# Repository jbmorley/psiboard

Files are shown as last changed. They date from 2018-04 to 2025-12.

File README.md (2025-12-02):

# PsiBoard



Psion Series 5 based bluetooth keyboard.



## BOM

### FFC Connector

https://www.digikey.com/en/products/detail/molex/0524372271/3262899

22 Position FFC, FPC Connector Contacts, Bottom 0.020" (0.50mm) Surface Mount, Right Angle

### Reset Switch

https://www.digikey.com/en/products/detail/panasonic-electronic-components/EVQ-P7A01P/4429447

## Development

### Useful Links

- [ZMK Firmware - List of Keycodes](https://zmk.dev/docs/keymaps/list-of-keycodes)
- [ZMK Firmware - Power Management Configuration](https://zmk.dev/docs/config/power)
- [Pro Micro Pinout](https://learn.sparkfun.com/tutorials/pro-micro--fio-v3-hookup-guide/all)

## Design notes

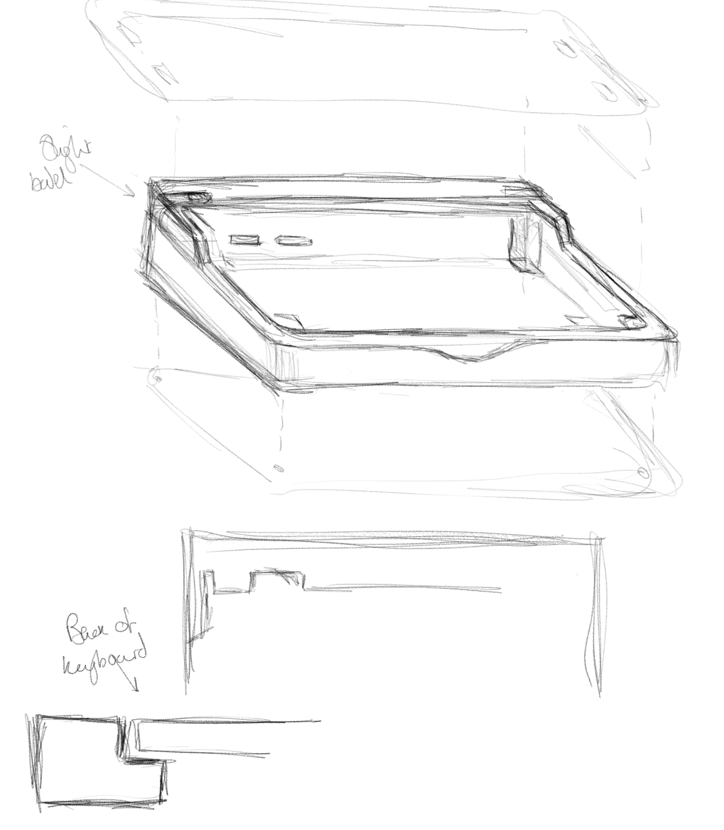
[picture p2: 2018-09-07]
reference/design.png

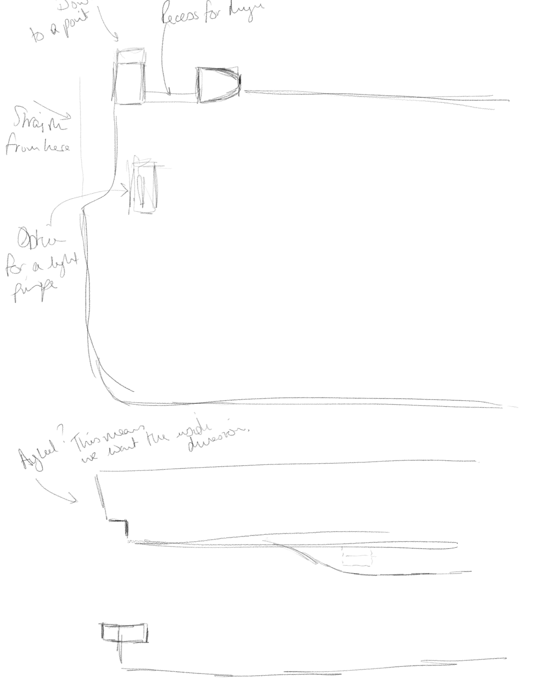
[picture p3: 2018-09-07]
reference/hinge.png

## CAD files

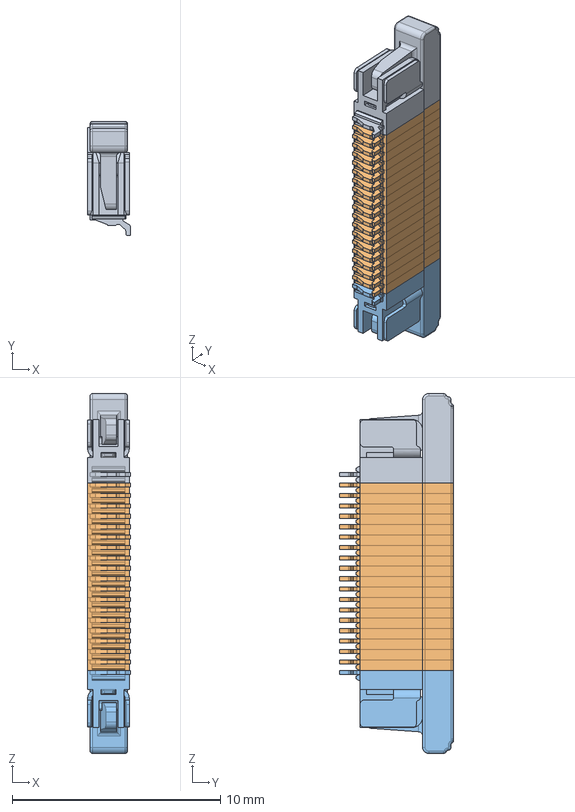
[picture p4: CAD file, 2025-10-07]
pcb/models/f32q_20pin_asm.stp
2.05 x 5.50 x 17.3 mm
F32Q_L
F32Q_M x 18
F32Q_R

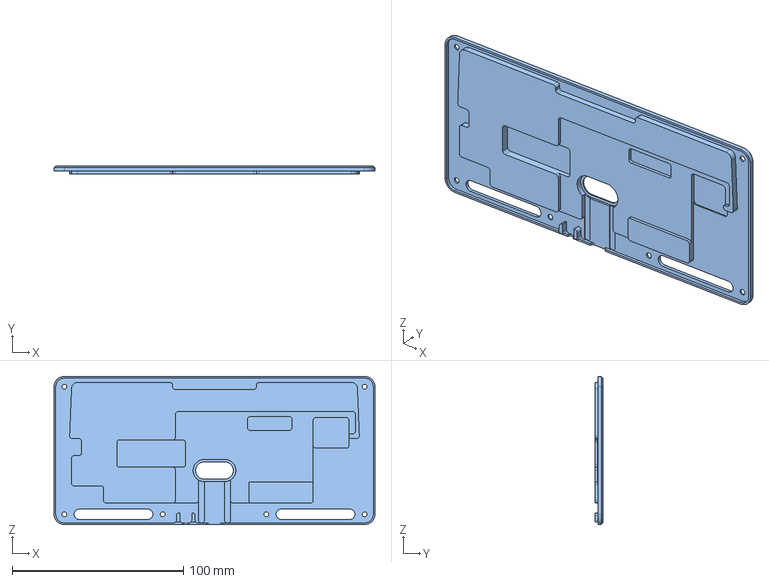
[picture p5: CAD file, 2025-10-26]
manufacture/Keyboard Bottom CNC.step
187.5 x 4.80 x 86.5 mm

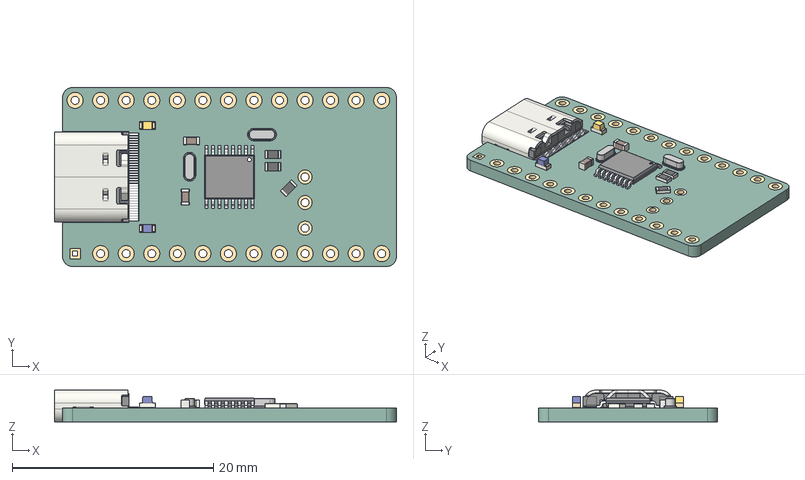
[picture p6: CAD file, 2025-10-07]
pcb/components/nicenano/nicenano.step
34.0 x 17.8 x 3.16 mm
nice!nano v1.0_1
USB_C_Receptacle_16P_TopMnt_Horizontal_GCT_USB4105-xx-A
USB_C_Receptacle_16P_TopMnt_Horizontal_GCT_USB4105-xx-A001
USB_C_Receptacle_16P_TopMnt_Horizontal_GCT_USB4105-xx-A002
USB_C_Receptacle_16P_TopMnt_Horizontal_GCT_USB4105-xx-A003
USB_C_Receptacle_16P_TopMnt_Horizontal_GCT_USB4105-xx-A004
USB_C_Receptacle_16P_TopMnt_Horizontal_GCT_USB4105-xx-A005
USB_C_Receptacle_16P_TopMnt_Horizontal_GCT_USB4105-xx-A006
USB_C_Receptacle_16P_TopMnt_Horizontal_GCT_USB4105-xx-A007
USB_C_Receptacle_16P_TopMnt_Horizontal_GCT_USB4105-xx-A008
USB_C_Receptacle_16P_TopMnt_Horizontal_GCT_USB4105-xx-A009
USB_C_Receptacle_16P_TopMnt_Horizontal_GCT_USB4105-xx-A010
USB_C_Receptacle_16P_TopMnt_Horizontal_GCT_USB4105-xx-A011
USB_C_Receptacle_16P_TopMnt_Horizontal_GCT_USB4105-xx-A012
USB_C_Receptacle_16P_TopMnt_Horizontal_GCT_USB4105-xx-A013
USB_C_Receptacle_16P_TopMnt_Horizontal_GCT_USB4105-xx-A014
USB_C_Receptacle_16P_TopMnt_Horizontal_GCT_USB4105-xx-A015
USB_C_Receptacle_16P_TopMnt_Horizontal_GCT_USB4105-xx-A016
USB_C_Receptacle_16P_TopMnt_Horizontal_GCT_USB4105-xx-A017
USB_C_Receptacle_16P_TopMnt_Horizontal_GCT_USB4105-xx-A018
USB_C_Receptacle_16P_TopMnt_Horizontal_GCT_USB4105-xx-A019
USB_C_Receptacle_16P_TopMnt_Horizontal_GCT_USB4105-xx-A020
USB_C_Receptacle_16P_TopMnt_Horizontal_GCT_USB4105-xx-A021
USB_C_Receptacle_16P_TopMnt_Horizontal_GCT_USB4105-xx-A022
USB_C_Receptacle_16P_TopMnt_Horizontal_GCT_USB4105-xx-A023
USB_C_Receptacle_16P_TopMnt_Horizontal_GCT_USB4105-xx-A024
USB_C_Receptacle_16P_TopMnt_Horizontal_GCT_USB4105-xx-A025
USB_C_Receptacle_16P_TopMnt_Horizontal_GCT_USB4105-xx-A026
USB_C_Receptacle_16P_TopMnt_Horizontal_GCT_USB4105-xx-A027
USB_C_Receptacle_16P_TopMnt_Horizontal_GCT_USB4105-xx-A028
USB_C_Receptacle_16P_TopMnt_Horizontal_GCT_USB4105-xx-A029
USB_C_Receptacle_16P_TopMnt_Horizontal_GCT_USB4105-xx-A030
USB_C_Receptacle_16P_TopMnt_Horizontal_GCT_USB4105-xx-A031
USB_C_Receptacle_16P_TopMnt_Horizontal_GCT_USB4105-xx-A032
USB_C_Receptacle_16P_TopMnt_Horizontal_GCT_USB4105-xx-A033
USB_C_Receptacle_16P_TopMnt_Horizontal_GCT_USB4105-xx-A034
USB_C_Receptacle_16P_TopMnt_Horizontal_GCT_USB4105-xx-A035
Pin9
Pin10
Pin12
Pin11
Pin13
Pin14
Pin15
Pin16
Pin8
Pin7
Pin6
Pin5
Pin4
Pin3
Pin2
Pin1
LED_0603_1608Metric_ON
C_0603_1608Metric x 2
LED_0603_1608Metric_ON_1
Crystal Oscillator x 2
R_0603_1608Metric x 4

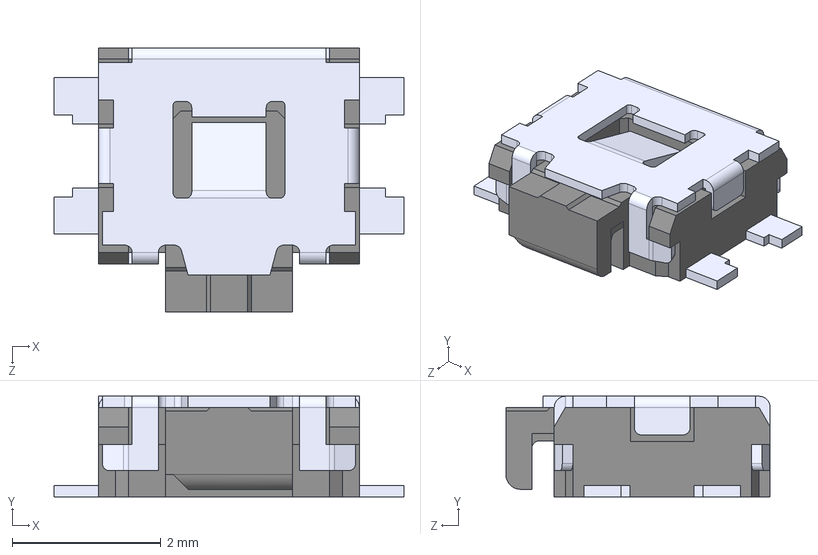
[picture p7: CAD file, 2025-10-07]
pcb/EVQ_P7A01P/EVQ-P7A01P.step
4.70 x 1.35 x 3.55 mm

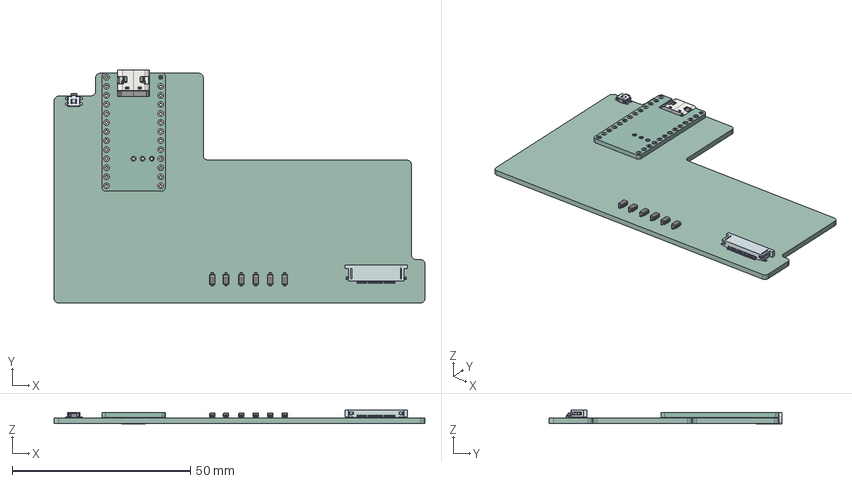
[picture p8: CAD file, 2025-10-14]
pcb/psiboard.step
104.1 x 65.4 x 3.83 mm
D_SOD-123 x 6
EVQ-P7A01P
nice!nano v1.0
USB_C_Receptacle_16P_TopMnt_Horizontal_GCT_USB4105-xx-A
USB_C_Receptacle_16P_TopMnt_Horizontal_GCT_USB4105-xx-A001
USB_C_Receptacle_16P_TopMnt_Horizontal_GCT_USB4105-xx-A002
USB_C_Receptacle_16P_TopMnt_Horizontal_GCT_USB4105-xx-A003
USB_C_Receptacle_16P_TopMnt_Horizontal_GCT_USB4105-xx-A004
USB_C_Receptacle_16P_TopMnt_Horizontal_GCT_USB4105-xx-A005
USB_C_Receptacle_16P_TopMnt_Horizontal_GCT_USB4105-xx-A006
USB_C_Receptacle_16P_TopMnt_Horizontal_GCT_USB4105-xx-A007
USB_C_Receptacle_16P_TopMnt_Horizontal_GCT_USB4105-xx-A008
USB_C_Receptacle_16P_TopMnt_Horizontal_GCT_USB4105-xx-A009
USB_C_Receptacle_16P_TopMnt_Horizontal_GCT_USB4105-xx-A010
USB_C_Receptacle_16P_TopMnt_Horizontal_GCT_USB4105-xx-A011
USB_C_Receptacle_16P_TopMnt_Horizontal_GCT_USB4105-xx-A012
USB_C_Receptacle_16P_TopMnt_Horizontal_GCT_USB4105-xx-A013
USB_C_Receptacle_16P_TopMnt_Horizontal_GCT_USB4105-xx-A014
USB_C_Receptacle_16P_TopMnt_Horizontal_GCT_USB4105-xx-A015
USB_C_Receptacle_16P_TopMnt_Horizontal_GCT_USB4105-xx-A016
USB_C_Receptacle_16P_TopMnt_Horizontal_GCT_USB4105-xx-A017
USB_C_Receptacle_16P_TopMnt_Horizontal_GCT_USB4105-xx-A018
USB_C_Receptacle_16P_TopMnt_Horizontal_GCT_USB4105-xx-A019
USB_C_Receptacle_16P_TopMnt_Horizontal_GCT_USB4105-xx-A020
USB_C_Receptacle_16P_TopMnt_Horizontal_GCT_USB4105-xx-A021
USB_C_Receptacle_16P_TopMnt_Horizontal_GCT_USB4105-xx-A022
USB_C_Receptacle_16P_TopMnt_Horizontal_GCT_USB4105-xx-A023
USB_C_Receptacle_16P_TopMnt_Horizontal_GCT_USB4105-xx-A024
USB_C_Receptacle_16P_TopMnt_Horizontal_GCT_USB4105-xx-A025
USB_C_Receptacle_16P_TopMnt_Horizontal_GCT_USB4105-xx-A026
USB_C_Receptacle_16P_TopMnt_Horizontal_GCT_USB4105-xx-A027
USB_C_Receptacle_16P_TopMnt_Horizontal_GCT_USB4105-xx-A028
USB_C_Receptacle_16P_TopMnt_Horizontal_GCT_USB4105-xx-A029
USB_C_Receptacle_16P_TopMnt_Horizontal_GCT_USB4105-xx-A030
USB_C_Receptacle_16P_TopMnt_Horizontal_GCT_USB4105-xx-A031
USB_C_Receptacle_16P_TopMnt_Horizontal_GCT_USB4105-xx-A032
USB_C_Receptacle_16P_TopMnt_Horizontal_GCT_USB4105-xx-A033
USB_C_Receptacle_16P_TopMnt_Horizontal_GCT_USB4105-xx-A034
USB_C_Receptacle_16P_TopMnt_Horizontal_GCT_USB4105-xx-A035
Pin9
Pin10
Pin12
Pin11
Pin13
Pin14
Pin15
Pin16
Pin8
Pin7
Pin6
Pin5
Pin4
Pin3
Pin2
Pin1
LED_0603_1608Metric_ON v1
Capacitor v1 x 2
LED_0603_1608Metric_ON v1(Mirror)
Crystal Oscillator v3 x 2
Resistor_0603_1608Metric v1 x 4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

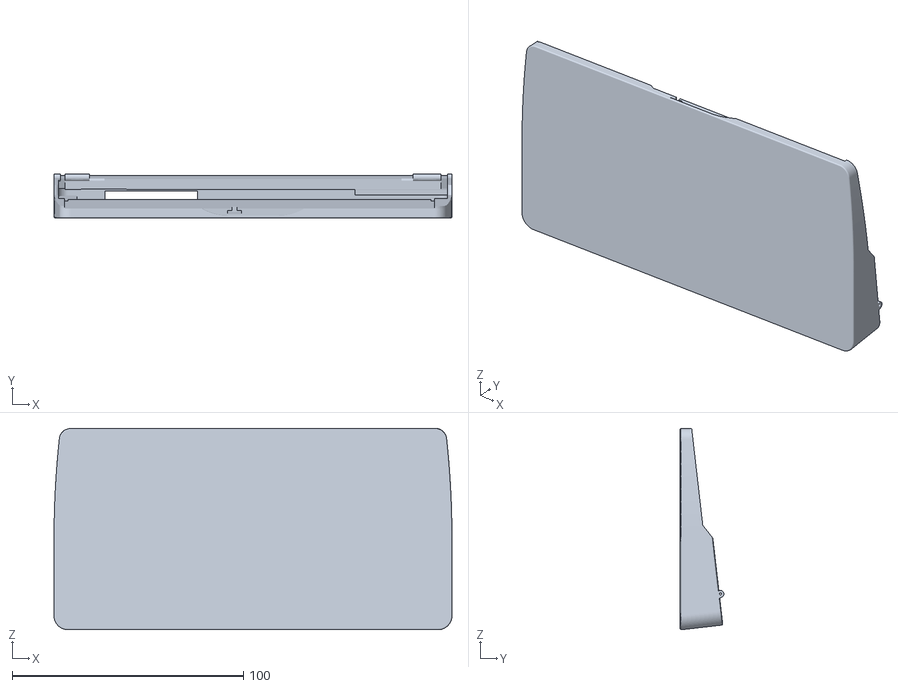
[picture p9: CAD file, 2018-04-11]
v1/case/stl/Case v3.stl
172.0 x 18.9 x 87.1

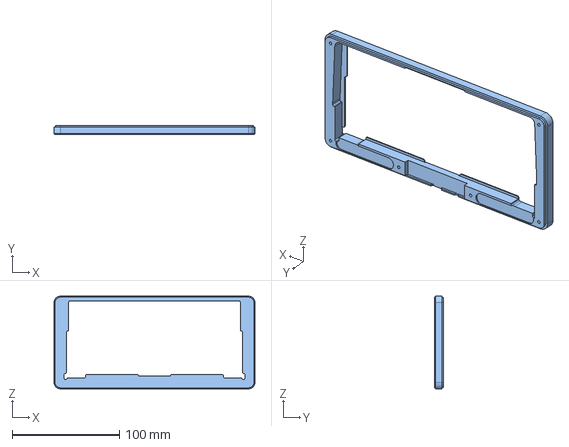
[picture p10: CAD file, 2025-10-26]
manufacture/Keyboard Top CNC.step
187.5 x 8.55 x 86.5 mm

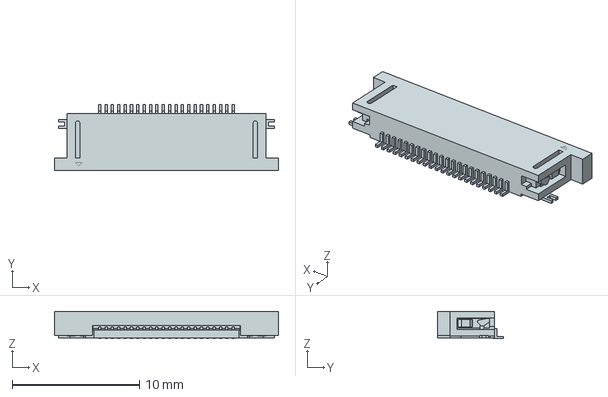
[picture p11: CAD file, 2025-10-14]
pcb/components/524372271/524372271.stp
17.6 x 5.20 x 2.16 mm

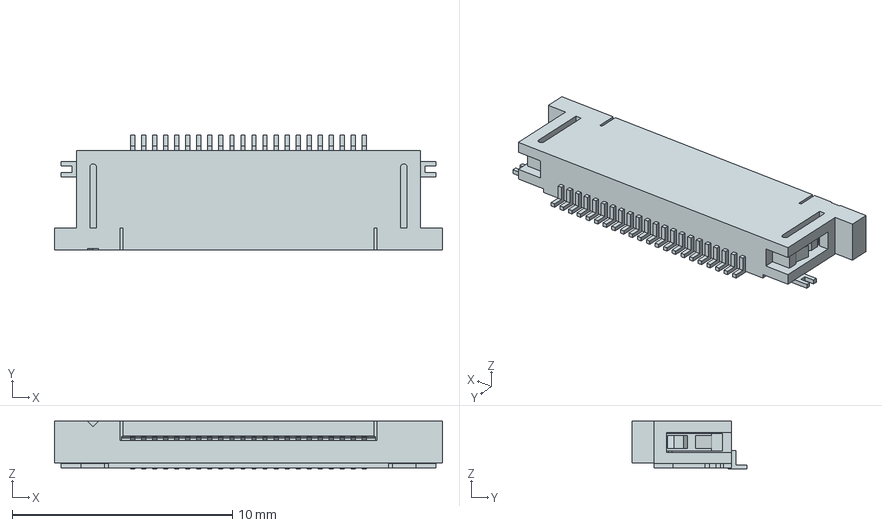
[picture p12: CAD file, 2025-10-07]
pcb/models/524352271.stp
17.6 x 5.20 x 2.16 mm

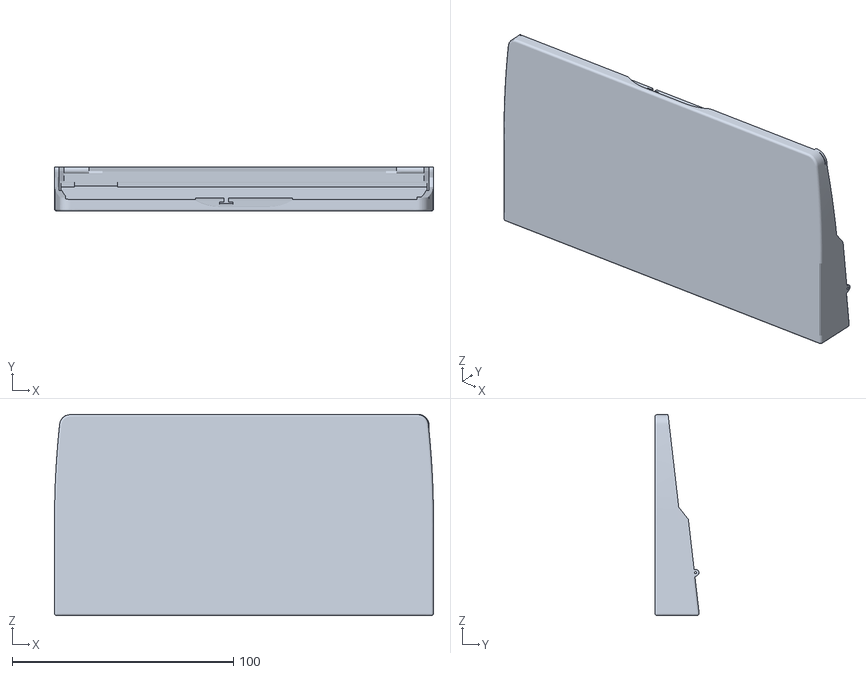
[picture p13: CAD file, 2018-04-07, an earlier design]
v1/case/stl/Case v2.stl
171.3 x 20.0 x 91.0

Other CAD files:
manufacture/Keyboard Top FDM.stl
manufacture/Bluetooth Window.stl
manufacture/Keyboard Bottom FDM.stl
manufacture/Hinge Left.stl
manufacture/Reset Button.stl
manufacture/Hinge Right.stl
manufacture/pcb.step
manufacture/Foot.stl
v1/case/fusion/Psion Keyboard Case.f3d
v1/case/fusion/Psion Keyboard.f3d
v1/case/stl/Case v1.stl

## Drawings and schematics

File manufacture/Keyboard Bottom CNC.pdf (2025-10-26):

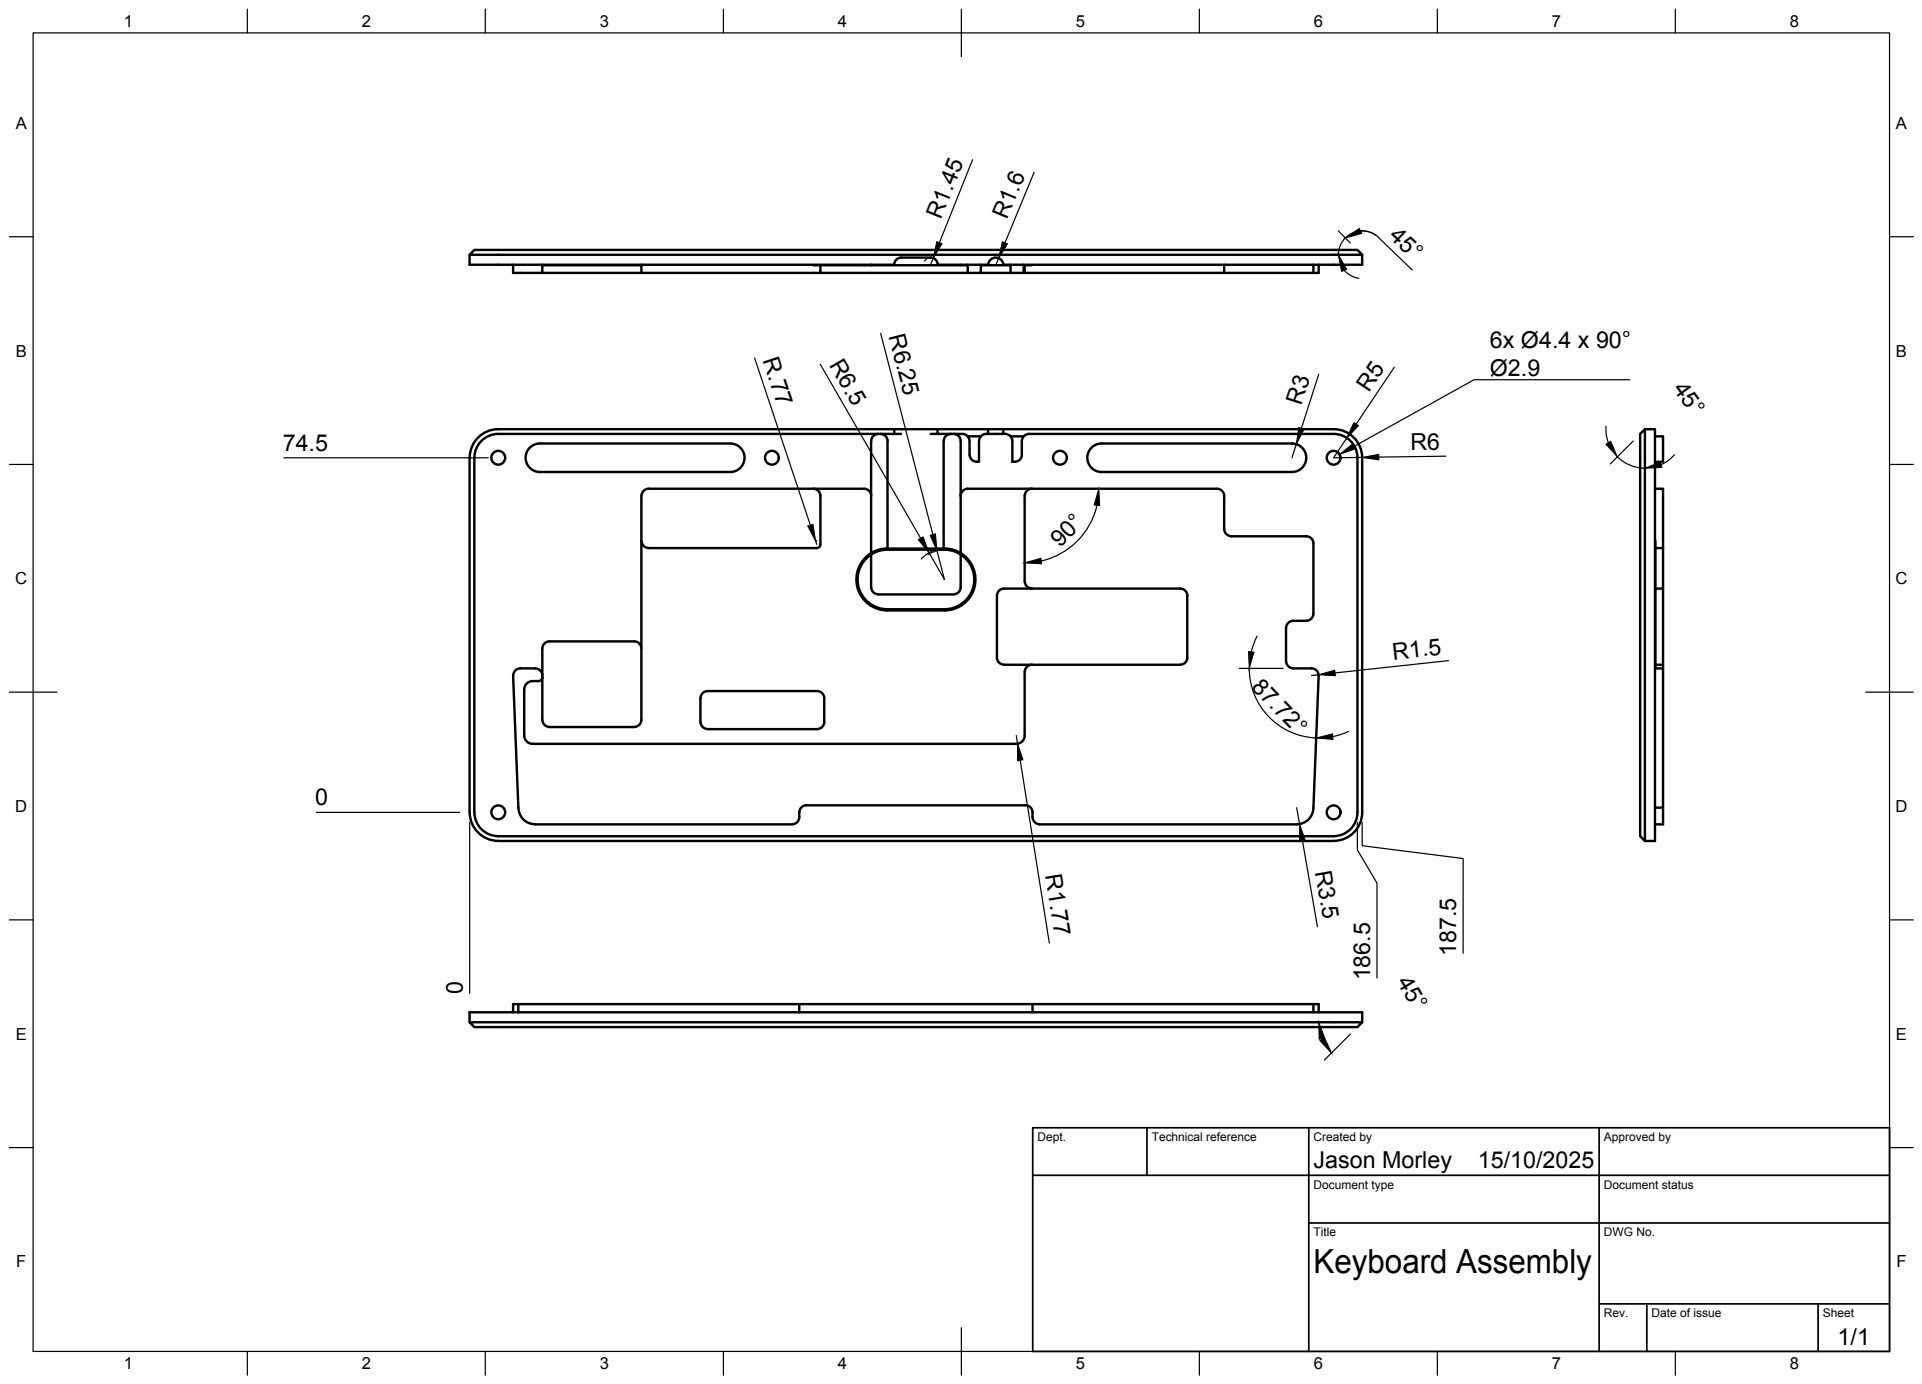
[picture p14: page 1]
Title; DWG No.; Rev.; Date of issue; Sheet; Keyboard Assembly

Dept. | Technical reference | Created by Jason Morley 15/10/2025 | Approved by

Document type | Document status

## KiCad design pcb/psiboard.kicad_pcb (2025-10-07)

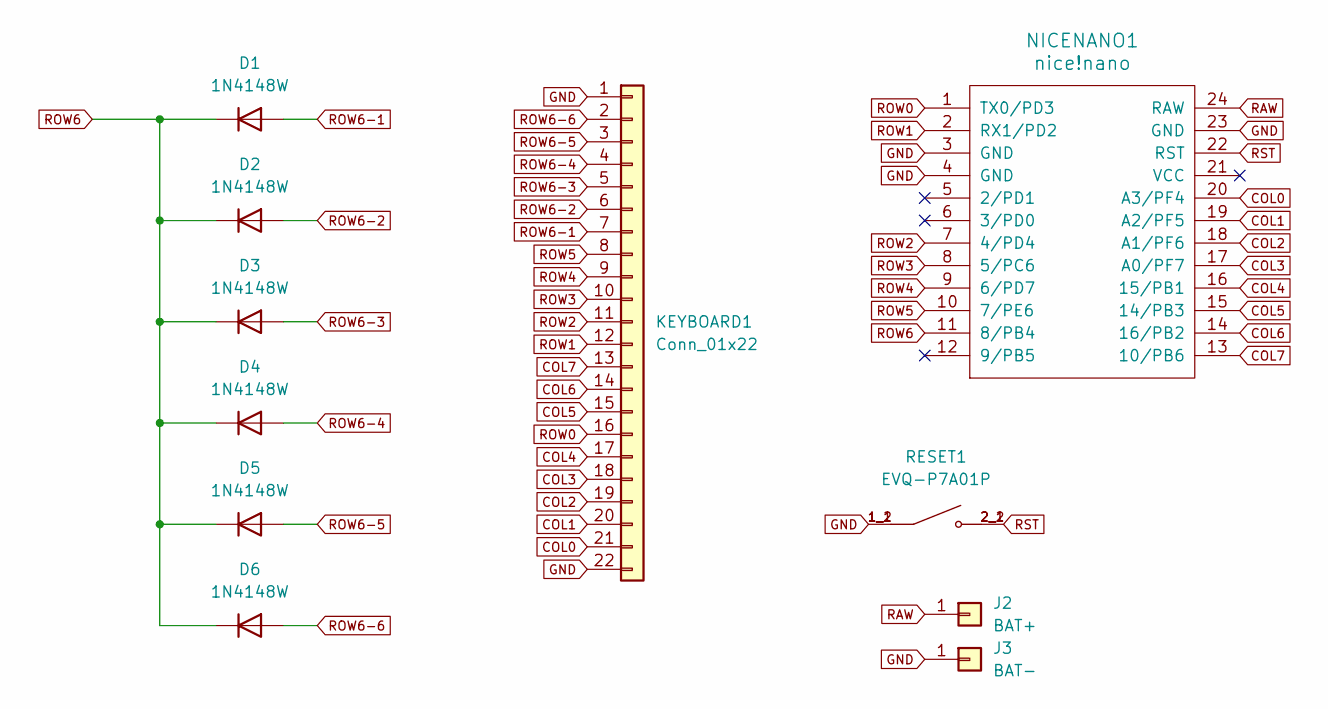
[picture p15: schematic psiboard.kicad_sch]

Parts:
D1, D2, D3, D4, D5, D6: 1N4148W; D_SOD-123
J2: BAT+; TestPoint_Pad_2.0x2.0mm
J3: BAT-; TestPoint_Pad_2.0x2.0mm
KEYBOARD1: Conn_01x22; CON_524352271_MOL
NICENANO1: nice!nano
RESET1: EVQ-P7A01P; SW_EVQ-P7A01P; PARTREV 2022.4

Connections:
COL0: KEYBOARD1.21, NICENANO1.20 (A3/PF4)
COL1: KEYBOARD1.20, NICENANO1.19 (A2/PF5)
COL2: KEYBOARD1.19, NICENANO1.18 (A1/PF6)
COL3: KEYBOARD1.18, NICENANO1.17 (A0/PF7)
COL4: KEYBOARD1.17, NICENANO1.16 (15/PB1)
COL5: KEYBOARD1.15, NICENANO1.15 (14/PB3)
COL6: KEYBOARD1.14, NICENANO1.14 (16/PB2)
COL7: KEYBOARD1.13, NICENANO1.13 (10/PB6)
GND: J3.1, KEYBOARD1.1, KEYBOARD1.22, NICENANO1.3 (GND), NICENANO1.4 (GND), NICENANO1.23 (GND), RESET1.1_1, RESET1.1_2
RAW: J2.1, NICENANO1.24 (RAW)
ROW0: KEYBOARD1.16, NICENANO1.1 (TX0/PD3)
ROW1: KEYBOARD1.12, NICENANO1.2 (RX1/PD2)
ROW2: KEYBOARD1.11, NICENANO1.7 (4/PD4)
ROW3: KEYBOARD1.10, NICENANO1.8 (5/PC6)
ROW4: KEYBOARD1.9, NICENANO1.9 (6/PD7)
ROW5: KEYBOARD1.8, NICENANO1.10 (7/PE6)
ROW6: D1.1 (K), D2.1 (K), D3.1 (K), D4.1 (K), D5.1 (K), D6.1 (K), NICENANO1.11 (8/PB4)
ROW6-1: D1.2 (A), KEYBOARD1.7
ROW6-2: D2.2 (A), KEYBOARD1.6
ROW6-3: D3.2 (A), KEYBOARD1.5
ROW6-4: D4.2 (A), KEYBOARD1.4
ROW6-5: D5.2 (A), KEYBOARD1.3
ROW6-6: D6.2 (A), KEYBOARD1.2
RST: NICENANO1.22 (RST), RESET1.2_1, RESET1.2_2

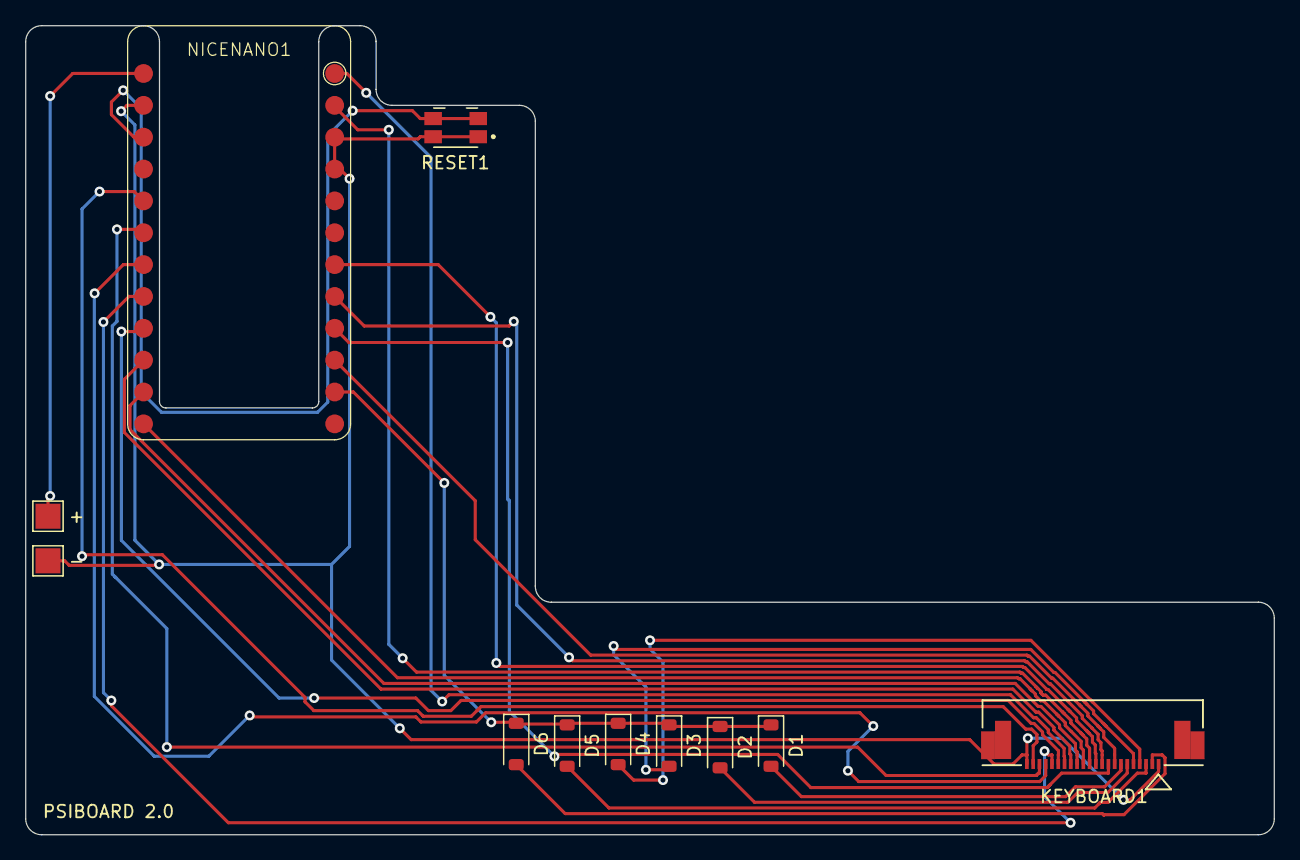
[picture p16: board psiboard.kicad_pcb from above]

Board: 2 copper layers, 99.6 x 64.5 mm, 11 parts (0 on the bottom side), 24 nets.

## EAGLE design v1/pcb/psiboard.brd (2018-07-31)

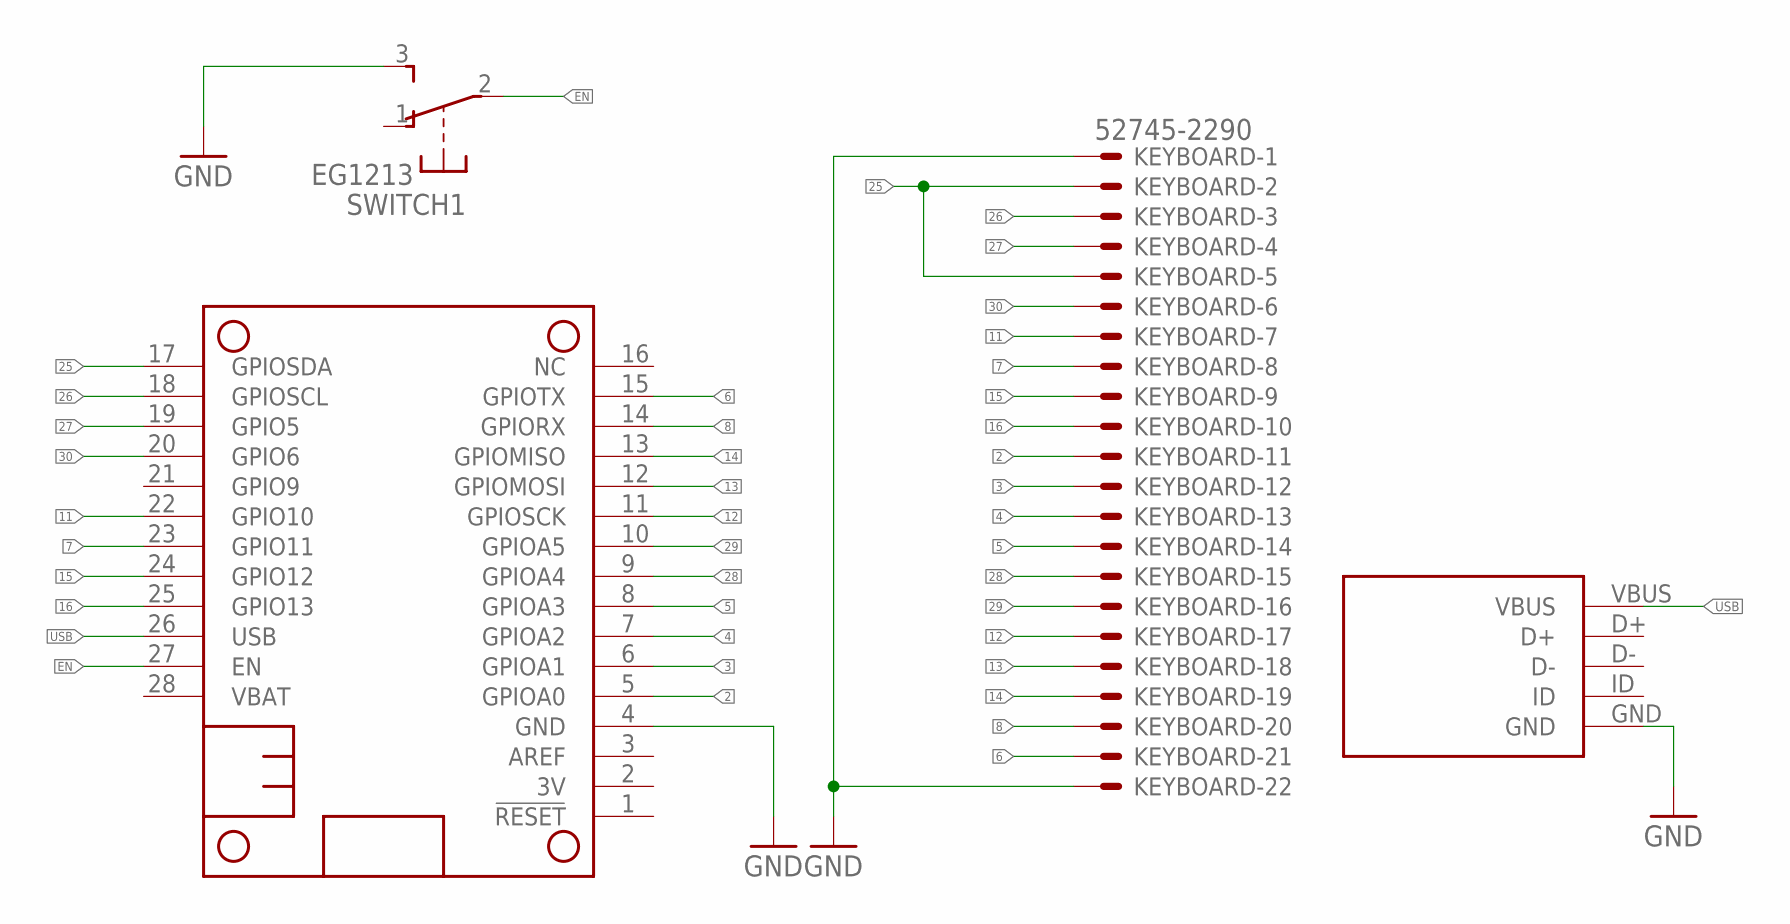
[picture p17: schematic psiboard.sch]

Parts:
FEATHER: FEATHERWING_NODIM; FEATHERWING_DIM
KEYBOARD: 52745-2290
SWITCH: EG1213
U$2: USB_MICRO_PWR; MICROBUILDER_4UCONN_20329

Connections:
2: FEATHER.5 (GPIOA0), KEYBOARD.11
3: FEATHER.6 (GPIOA1), KEYBOARD.12
4: FEATHER.7 (GPIOA2), KEYBOARD.13
5: FEATHER.8 (GPIOA3), KEYBOARD.14
6: FEATHER.15 (GPIOTX), KEYBOARD.21
7: FEATHER.23 (GPIO11), KEYBOARD.8
8: FEATHER.14 (GPIORX), KEYBOARD.20
11: FEATHER.22 (GPIO10), KEYBOARD.7
12: FEATHER.11 (GPIOSCK), KEYBOARD.17
13: FEATHER.12 (GPIOMOSI), KEYBOARD.18
14: FEATHER.13 (GPIOMISO), KEYBOARD.19
15: FEATHER.24 (GPIO12), KEYBOARD.9
16: FEATHER.25 (GPIO13), KEYBOARD.10
25: FEATHER.17 (GPIOSDA), KEYBOARD.2, KEYBOARD.5
26: FEATHER.18 (GPIOSCL), KEYBOARD.3
27: FEATHER.19 (GPIO5), KEYBOARD.4
28: FEATHER.9 (GPIOA4), KEYBOARD.15
29: FEATHER.10 (GPIOA5), KEYBOARD.16
30: FEATHER.20 (GPIO6), KEYBOARD.6
EN: FEATHER.27 (EN), SWITCH.2
GND: FEATHER.4 (GND), KEYBOARD.1, KEYBOARD.22, SWITCH.3 (S), U$2.GND
USB: FEATHER.26 (USB), U$2.VBUS

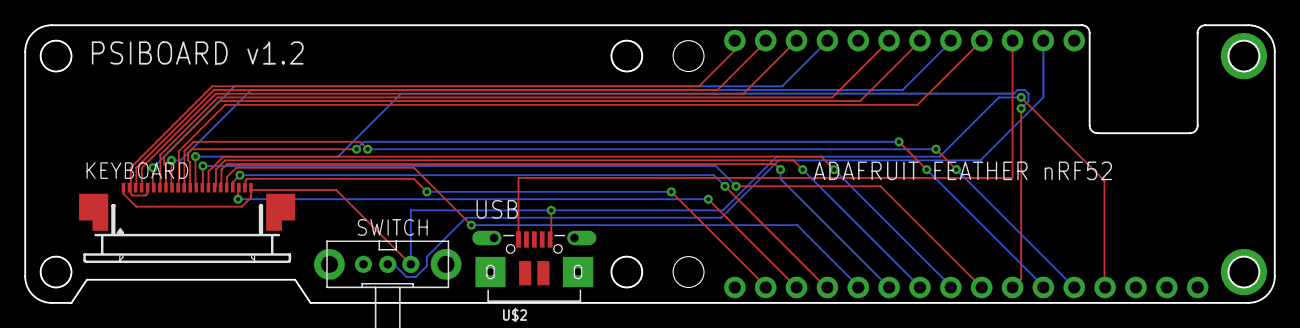
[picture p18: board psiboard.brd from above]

Board: 2 copper layers, 102.9 x 22.9 mm, 4 parts (1 on the bottom side), 22 nets.

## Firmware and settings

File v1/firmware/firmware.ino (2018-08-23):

/*********************************************************************
  This is an example for our nRF52 based Bluefruit LE modules

  Pick one up today in the adafruit shop!

  Adafruit invests time and resources providing this open source code,
  please support Adafruit and open-source hardware by purchasing
  products from Adafruit!

  MIT license, check LICENSE for more information
  All text above, and the splash screen below must be included in
  any redistribution
*********************************************************************/
#include <bluefruit.h>

BLEDis bledis;
BLEHidAdafruit blehid;

#define KEYBOARD_01 25
#define KEYBOARD_02 26
#define KEYBOARD_03 27
#define KEYBOARD_04 25
#define KEYBOARD_05 30
#define KEYBOARD_06 11
#define KEYBOARD_07 7
#define KEYBOARD_08 15
#define KEYBOARD_09 16
#define KEYBOARD_10 2
#define KEYBOARD_11 3
#define KEYBOARD_12 4
#define KEYBOARD_13 5
#define KEYBOARD_14 28
#define KEYBOARD_15 29
#define KEYBOARD_16 12
#define KEYBOARD_17 13
#define KEYBOARD_18 14
#define KEYBOARD_19 8
#define KEYBOARD_20 6

# define MAX_COLUMNS 11
int COLUMNS[] = {
  KEYBOARD_15,
  KEYBOARD_11,
  KEYBOARD_10,
  KEYBOARD_09,
  KEYBOARD_08,
  KEYBOARD_07,
  KEYBOARD_06,
  KEYBOARD_05,
  KEYBOARD_04,
  KEYBOARD_03,
  KEYBOARD_02,
  };

#define MAX_ROWS 8
int ROWS[] = {
  KEYBOARD_20,
  KEYBOARD_19,
  KEYBOARD_18,
  KEYBOARD_17,
  KEYBOARD_16,
  KEYBOARD_14,
  KEYBOARD_13,
  KEYBOARD_12,
  };

#define KEY_NONE HID_KEY_A

#define COL_COUNT 11
#define ROW_COUNT 8

static uint8_t CHARACTER_MAP[COL_COUNT][ROW_COUNT] = {
  { KEY_NONE,            HID_KEY_Z,           HID_KEY_H,          HID_KEY_TAB,          HID_KEY_1, HID_KEY_U,        HID_KEY_Q,      HID_KEY_7           },
  { HID_KEY_SPACE,       HID_KEY_X,           HID_KEY_J,          HID_KEY_A,            HID_KEY_2, HID_KEY_I,        HID_KEY_W,      HID_KEY_8,          },
  { HID_KEY_ARROW_UP,    HID_KEY_C,           HID_KEY_K,          HID_KEY_S,            HID_KEY_3, HID_KEY_O,        HID_KEY_E,      HID_KEY_9,          },
  { HID_KEY_COMMA,       HID_KEY_V,           HID_KEY_M,          HID_KEY_D,            HID_KEY_4, HID_KEY_P,        HID_KEY_R,      HID_KEY_0,          },
  { HID_KEY_ARROW_LEFT,  HID_KEY_B,           HID_KEY_PERIOD,     HID_KEY_F,            HID_KEY_5, HID_KEY_L,        HID_KEY_T,      HID_KEY_BACKSPACE,  },
  { HID_KEY_ARROW_RIGHT, HID_KEY_N,           HID_KEY_ARROW_DOWN, HID_KEY_G,            HID_KEY_6, HID_KEY_RETURN,   HID_KEY_Y,      HID_KEY_APOSTROPHE, },
  { HID_KEY_SHIFT_LEFT,  KEY_NONE,            KEY_NONE,           KEY_NONE,             KEY_NONE,  KEY_NONE,         KEY_NONE,       KEY_NONE,           },
  { KEY_NONE,            HID_KEY_SHIFT_RIGHT, KEY_NONE,           KEY_NONE,             KEY_NONE,  KEY_NONE,         KEY_NONE,       KEY_NONE,           },
  { KEY_NONE,            KEY_NONE,            HID_KEY_ALT_LEFT,   HID_KEY_CONTROL_LEFT, KEY_NONE,  KEY_NONE,         KEY_NONE,       KEY_NONE,           },
  { KEY_NONE,            KEY_NONE,            KEY_NONE,           KEY_NONE,             KEY_NONE,  HID_KEY_GUI_LEFT, KEY_NONE,       KEY_NONE,           },
  { KEY_NONE,            KEY_NONE,            KEY_NONE,           KEY_NONE,             KEY_NONE,  KEY_NONE,         HID_KEY_ESCAPE, KEY_NONE,           },
};

typedef enum {
  EventTypeKey,
  EventTypeCharacter,
  EventTypeConsumerKey,
} EventType;

struct Event {
  EventType type;
  uint16_t data;
};

struct ModifierBehavior {
  uint8_t modifiers;
  uint8_t keyCode;
  Event event;
};

#define SHIFT_BEHAVIOR_COUNT 25
static ModifierBehavior ShiftBehavior[SHIFT_BEHAVIOR_COUNT] = {
  { .modifiers = KEYBOARD_MODIFIER_LEFTSHIFT | KEYBOARD_MODIFIER_RIGHTSHIFT, .keyCode = HID_KEY_COMMA,       .event = { .type = EventTypeKey,         .data = HID_KEY_SLASH } },
  { .modifiers = KEYBOARD_MODIFIER_LEFTSHIFT | KEYBOARD_MODIFIER_RIGHTSHIFT, .keyCode = HID_KEY_PERIOD,      .event = { .type = EventTypeCharacter,   .data = '?'           } },
  { .modifiers = KEYBOARD_MODIFIER_LEFTSHIFT | KEYBOARD_MODIFIER_RIGHTSHIFT, .keyCode = HID_KEY_APOSTROPHE,  .event = { .type = EventTypeCharacter,   .data = '~'           } },
  { .modifiers = KEYBOARD_MODIFIER_LEFTSHIFT | KEYBOARD_MODIFIER_RIGHTSHIFT, .keyCode = HID_KEY_2,           .event = { .type = EventTypeCharacter,   .data = '"'           } },
  { .modifiers = KEYBOARD_MODIFIER_LEFTALT,                                  .keyCode = HID_KEY_Y,           .event = { .type = EventTypeKey,         .data = HID_KEY_KEYPAD_MULTIPLY                 } },
  { .modifiers = KEYBOARD_MODIFIER_LEFTALT,                                  .keyCode = HID_KEY_U,           .event = { .type = EventTypeKey,         .data = HID_KEY_KEYPAD_DIVIDE                   } },
  { .modifiers = KEYBOARD_MODIFIER_LEFTALT,                                  .keyCode = HID_KEY_I,           .event = { .type = EventTypeKey,         .data = HID_KEY_KEYPAD_ADD                      } },
  { .modifiers = KEYBOARD_MODIFIER_LEFTALT,                                  .keyCode = HID_KEY_O,           .event = { .type = EventTypeKey,         .data = HID_KEY_KEYPAD_SUBTRACT                 } },
  { .modifiers = KEYBOARD_MODIFIER_LEFTALT,                                  .keyCode = HID_KEY_P,           .event = { .type = EventTypeKey,         .data = HID_KEY_KEYPAD_EQUAL                    } },
  { .modifiers = KEYBOARD_MODIFIER_LEFTALT,                                  .keyCode = HID_KEY_1,           .event = { .type = EventTypeCharacter,   .data = '_'                                     } },
  { .modifiers = KEYBOARD_MODIFIER_LEFTALT,                                  .keyCode = HID_KEY_2,           .event = { .type = EventTypeCharacter,   .data = '#'                                     } },
  { .modifiers = KEYBOARD_MODIFIER_LEFTALT,                                  .keyCode = HID_KEY_3,           .event = { .type = EventTypeKey,         .data = HID_KEY_BACKSLASH                       } },
  { .modifiers = KEYBOARD_MODIFIER_LEFTALT,                                  .keyCode = HID_KEY_4,           .event = { .type = EventTypeCharacter,   .data = '@'                                     } },
  { .modifiers = KEYBOARD_MODIFIER_LEFTALT,                                  .keyCode = HID_KEY_5,           .event = { .type = EventTypeCharacter,   .data = '<'                                     } },
  { .modifiers = KEYBOARD_MODIFIER_LEFTALT,                                  .keyCode = HID_KEY_6,           .event = { .type = EventTypeCharacter,   .data = '>'                                     } },
  { .modifiers = KEYBOARD_MODIFIER_LEFTALT,                                  .keyCode = HID_KEY_7,           .event = { .type = EventTypeKey,         .data = HID_KEY_BRACKET_LEFT                    } },
  { .modifiers = KEYBOARD_MODIFIER_LEFTALT,                                  .keyCode = HID_KEY_8,           .event = { .type = EventTypeKey,         .data = HID_KEY_BRACKET_RIGHT                   } },
  { .modifiers = KEYBOARD_MODIFIER_LEFTALT,                                  .keyCode = HID_KEY_9,           .event = { .type = EventTypeCharacter,   .data = '{'                                     } },
  { .modifiers = KEYBOARD_MODIFIER_LEFTALT,                                  .keyCode = HID_KEY_0,           .event = { .type = EventTypeCharacter,   .data = '}'                                     } },
  { .modifiers = KEYBOARD_MODIFIER_LEFTALT,                                  .keyCode = HID_KEY_L,           .event = { .type = EventTypeCharacter,   .data = ';'                                     } },
  { .modifiers = KEYBOARD_MODIFIER_LEFTALT,                                  .keyCode = HID_KEY_APOSTROPHE,  .event = { .type = EventTypeCharacter,   .data = ':'                                     } },
//  { .modifiers = KEYBOARD_MODIFIER_LEFTALT,                                  .keyCode = HID_KEY_ARROW_LEFT,  .event = { .type = EventTypeKey,         .data = HID_KEY_HOME                            } },
//  { .modifiers = KEYBOARD_MODIFIER_LEFTALT,                                  .keyCode = HID_KEY_ARROW_RIGHT, .event = { .type = EventTypeKey,         .data = HID_KEY_END                             } },
//  { .modifiers = KEYBOARD_MODIFIER_LEFTALT,                                  .keyCode = HID_KEY_ARROW_UP,    .event = { .type = EventTypeKey,         .data = HID_KEY_PAGE_UP                         } },
//  { .modifiers = KEYBOARD_MODIFIER_LEFTALT,                                  .keyCode = HID_KEY_ARROW_DOWN,  .event = { .type = EventTypeKey,         .data = HID_KEY_PAGE_DOWN                       } },
  { .modifiers = KEYBOARD_MODIFIER_LEFTALT,                                  .keyCode = HID_KEY_TAB,         .event = { .type = EventTypeKey,         .data = HID_KEY_CAPS_LOCK                       } },
  { .modifiers = KEYBOARD_MODIFIER_LEFTALT,                                  .keyCode = HID_KEY_M,           .event = { .type = EventTypeConsumerKey, .data = HID_USAGE_CONSUMER_BRIGHTNESS_DECREMENT } },
  { .modifiers = KEYBOARD_MODIFIER_LEFTALT,                                  .keyCode = HID_KEY_PERIOD,      .event = { .type = EventTypeConsumerKey, .data = HID_USAGE_CONSUMER_BRIGHTNESS_INCREMENT } },
  { .modifiers = KEYBOARD_MODIFIER_LEFTALT,                                  .keyCode = HID_KEY_ESCAPE,      .event = { .type = EventTypeConsumerKey, .data = HID_USAGE_CONSUMER_POWER                } },
};

static uint8_t keyboardState[COL_COUNT][ROW_COUNT] = { 0 };

static uint8_t modifierState = 0;

void updateModifierState(uint8_t *modifierState, uint8_t modifier, bool down) {
  if (down) {
    *modifierState |= modifier;
  } else {
    *modifierState &= ~modifier;
  }
}

void sendEvent(Event event, bool down) {
  if (event.type == EventTypeKey) {
    if (down) {
      blehid.keyboardReport(0, event.data);
    } else {
      blehid.keyRelease();
    }
  } else if (event.type == EventTypeCharacter) {
    if (down) {
      blehid.keyPress(event.data);
    } else {
      blehid.keyRelease();
    }
  } else if (event.type == EventTypeConsumerKey) {
    if (down) { 
      blehid.consumerKeyPress(event.data);
    } else {
      blehid.consumerKeyRelease();
    }
  }
}

void sendKey(uint8_t keyCode, bool down) {

  if (keyCode == HID_KEY_SHIFT_LEFT) {
    updateModifierState(&modifierState, KEYBOARD_MODIFIER_LEFTSHIFT, down);
    return;
  }

  if (keyCode == HID_KEY_SHIFT_RIGHT) {
    updateModifierState(&modifierState, KEYBOARD_MODIFIER_RIGHTSHIFT, down);
    return;
  }

  if (keyCode == HID_KEY_ALT_LEFT) {
    updateModifierState(&modifierState, KEYBOARD_MODIFIER_LEFTALT, down);
    return;
  }

  if (keyCode == HID_KEY_GUI_LEFT) {
    updateModifierState(&modifierState, KEYBOARD_MODIFIER_LEFTGUI, down);
    return;
  }

  if (keyCode == HID_KEY_CONTROL_LEFT) {
    updateModifierState(&modifierState, KEYBOARD_MODIFIER_LEFTCTRL, down);
    return;
  }

  if (modifierState > 0) {
    ModifierBehavior behavior;
    bool found = false;
    for (int i = 0; i < SHIFT_BEHAVIOR_COUNT; i++) {
      ModifierBehavior loopBehavior = ShiftBehavior[i];
      if ((modifierState & loopBehavior.modifiers) &&
          (loopBehavior.keyCode == keyCode)) {
        behavior = loopBehavior;
        found = true;
        break;
      }
    }
    if (found) {
      sendEvent(behavior.event, down);
      return;
    }
  }
  
  if (down) {
    blehid.keyboardReport(modifierState, keyCode);
  } else {
    blehid.keyRelease();
  }
}

void setup()
{
  Bluefruit.begin();
  // Set max power. Accepted values are: -40, -30, -20, -16, -12, -8, -4, 0, 4
  Bluefruit.setTxPower(4);
  Bluefruit.setName("Psion Keyboard");

  // Configure and Start Device Information Service
  bledis.setManufacturer("InSeven Limited");
  bledis.setModel("Psion Keyboard");
  bledis.begin();

  /* Start BLE HID
     Note: Apple requires BLE device must have min connection interval >= 20m
     ( The smaller the connection interval the faster we could send data).
     However for HID and MIDI device, Apple could accept min connection interval
     up to 11.25 ms. Therefore BLEHidAdafruit::begin() will try to set the min and max
     connection interval to 11.25  ms and 15 ms respectively for best performance.
  */
  blehid.begin();

  /* Set connection interval (min, max) to your perferred value.
     Note: It is already set by BLEHidAdafruit::begin() to 11.25ms - 15ms
     min = 9*1.25=11.25 ms, max = 12*1.25= 15 ms
  */
  /* Bluefruit.setConnInterval(9, 12); */

  // Set up and start advertising
  startAdv();

  // Initialize the GPIO pins.

  for (int c = 0; c < MAX_COLUMNS; c++) {
    pinMode(COLUMNS[c], INPUT_PULLUP);
  }

  for (int r = 0; r < MAX_ROWS; r++) {
    pinMode(ROWS[r], INPUT_PULLUP);
  }

}

void startAdv(void)
{
  // Advertising packet
  Bluefruit.Advertising.addFlags(BLE_GAP_ADV_FLAGS_LE_ONLY_GENERAL_DISC_MODE);
  Bluefruit.Advertising.addTxPower();
  Bluefruit.Advertising.addAppearance(BLE_APPEARANCE_HID_KEYBOARD);

  // Include BLE HID service
  Bluefruit.Advertising.addService(blehid);

  // There is enough room for the dev name in the advertising packet
  Bluefruit.Advertising.addName();

  /* Start Advertising
     - Enable auto advertising if disconnected
     - Interval:  fast mode = 20 ms, slow mode = 152.5 ms
     - Timeout for fast mode is 30 seconds
     - Start(timeout) with timeout = 0 will advertise forever (until connected)

     For recommended advertising interval
     https://developer.apple.com/library/content/qa/qa1931/_index.html
  */
  Bluefruit.Advertising.restartOnDisconnect(true);
  Bluefruit.Advertising.setInterval(32, 244);    // in unit of 0.625 ms
  Bluefruit.Advertising.setFastTimeout(30);      // number of seconds in fast mode
  Bluefruit.Advertising.start(0);                // 0 = Don't stop advertising after n seconds
}

void loop()
{
  // Iterate over the columns, pulling each low in turn.
  for (int c = 0; c < MAX_COLUMNS; c++) {
    int column = COLUMNS[c];

    // Pull the column low.
    pinMode(column, OUTPUT);
    digitalWrite(column, LOW);
    delay(5); // TODO: Is this necessary

    // TODO: Consider delaying here to allow everything to become quiescent.

    // Iterate over the rows, reading their state.
    for (int r = 0; r < MAX_ROWS; r++) {
      
      int keyDown = (digitalRead(ROWS[r]) == LOW) ? 1 : 0;
      int currentKeyDown = keyboardState[c][r];
      
      if (keyDown != currentKeyDown) {
        char character = CHARACTER_MAP[c][r];
        if (character != HID_KEY_NONE) {
          sendKey(character, keyDown);
          keyboardState[c][r] = keyDown;
        }
      }
    }

    // Restore the column.
    pinMode(column, INPUT_PULLUP);
  }

  // Request CPU to enter low-power mode until an event/interrupt occurs
  waitForEvent();
}

/**
   RTOS Idle callback is automatically invoked by FreeRTOS
   when there are no active threads. E.g when loop() calls delay() and
   there is no bluetooth or hw event. This is the ideal place to handle
   background data.

   NOTE: FreeRTOS is configured as tickless idle mode. After this callback
   is executed, if there is time, freeRTOS kernel will go into low power mode.
   Therefore waitForEvent() should not be called in this callback.
   http://www.freertos.org/low-power-tickless-rtos.html

   WARNING: This function MUST NOT call any blocking FreeRTOS API
   such as delay(), xSemaphoreTake() etc ... for more information
   http://www.freertos.org/a00016.html
*/
void rtos_idle_callback(void)
{
  // Don't call any other FreeRTOS blocking API()
  // Perform background task(s) here
}

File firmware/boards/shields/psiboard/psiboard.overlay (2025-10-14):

#include <dt-bindings/zmk/matrix_transform.h>

/ {
    chosen {
        zmk,kscan = &kscan0;
        zmk,matrix_transform = &default_transform;
    };

    keys {
        compatible = "gpio-keys";
        soft_off_gpio_key: soft_off_gpio_key {
            gpios = <&pro_micro 8 (GPIO_ACTIVE_HIGH | GPIO_PULL_DOWN)>;
        };
    };

    soft_off_wakers {
        compatible = "zmk,soft-off-wakeup-sources";
        wakeup-sources = <&wakeup_scan>;
    };

    wakeup_scan: wakeup_scan {
        compatible = "zmk,gpio-key-wakeup-trigger";
        trigger = <&soft_off_gpio_key>;
        wakeup-source;
        extra-gpios = <&pro_micro 16 GPIO_ACTIVE_HIGH>;
    };

    kscan0: kscan_0 {
        compatible = "zmk,kscan-gpio-matrix";
        label = "KSCAN";
        diode-direction = "col2row";

        col-gpios
            = <&pro_micro 20 GPIO_ACTIVE_HIGH>  // COL0 (PM 21 -> KBD 20)
            , <&pro_micro 19 GPIO_ACTIVE_HIGH>  // COL1 (PM 20 -> KBD 19)
            , <&pro_micro 18 GPIO_ACTIVE_HIGH>  // COL2 (PM 19 -> KBD 18)
            , <&pro_micro 15 GPIO_ACTIVE_HIGH>  // COL3 (PM 18 -> KBD 17)
            , <&pro_micro 14 GPIO_ACTIVE_HIGH>  // COL4 (PM 15 -> KBD 16)
            , <&pro_micro 10 GPIO_ACTIVE_HIGH>  // COL5 (PM 14 -> KBD 14)
            , <&pro_micro  8 GPIO_ACTIVE_HIGH>  // COL6 (PM 16 -> KBD 13)
            , <&pro_micro  7 GPIO_ACTIVE_HIGH>  // COL7 (PM 10 -> KBD 12)
            ;

        row-gpios
            = <&pro_micro 16 (GPIO_ACTIVE_HIGH | GPIO_PULL_DOWN)>  // ROW0 (PM 1 -> KBD 15)
            , <&pro_micro  6 (GPIO_ACTIVE_HIGH | GPIO_PULL_DOWN)>  // ROW1 (PM 0 -> KBD 11)
            , <&pro_micro  5 (GPIO_ACTIVE_HIGH | GPIO_PULL_DOWN)>  // ROW2 (PM 4 -> KBD 10)
            , <&pro_micro  4 (GPIO_ACTIVE_HIGH | GPIO_PULL_DOWN)>  // ROW3 (PM 5 -> KBD 9)
            , <&pro_micro  0 (GPIO_ACTIVE_HIGH | GPIO_PULL_DOWN)>  // ROW4 (PM 6 -> KBD 8)
            , <&pro_micro  1 (GPIO_ACTIVE_HIGH | GPIO_PULL_DOWN)>  // ROW5 (PM 7 -> KBD 7)
            , <&pro_micro 21 (GPIO_ACTIVE_HIGH | GPIO_PULL_DOWN)>  // ROW6 (PM 8 -> KBD 1-6)
            ;
    };

    default_transform: matrix_transform {
        compatible = "zmk,matrix-transform";
        columns = <12>;
        rows = <5>;
        // ┌─────┬─────┬─────┬─────┬─────┬─────┬─────┬─────┬─────┬─────┬─────┬─────┐
        // │ Esc │  1  │  2  │  3  │  4  │  5  │  6  │  7  │  8  │  9  │  0  │ Del │
        // └──┬──┴──┬──┴──┬──┴──┬──┴──┬──┴──┬──┴──┬──┴──┬──┴──┬──┴──┬──┴──┬──┴─────┤
        //    │  Q  │  W  │  E  │  R  │  T  │  Y  │  U  │  I  │  O  │  P  │   Ent  │
        // ┌──┴──┬──┴──┬──┴──┬──┴──┬──┴──┬──┴──┬──┴──┬──┴──┬──┴──┬──┴──┬──┴──┐     │
        // │ Tab │  A  │  S  │  D  │  F  │  G  │  H  │  J  │  K  │  L  │ ' ~ │     │
        // └──┬──┴──┬──┴──┬──┴──┬──┴──┬──┴──┬──┴──┬──┴──┬──┴──┬──┴──┬──┴──┬──┴──┬──┘
        //    │ Sft │  Z  │  X  │  C  │  V  │  B  │  N  │  M  │ . ? │ Up  │ Sft │
        //    ├─────┼─────┼─────┼─────┴─────┴─────┴─────┼─────┼─────┼─────┼─────┤
        //    │ Ctl │ Fn  │ Mnu │         Space         │ , / │ Lft │ Dwn │ Rgt │
        //    └─────┴─────┴─────┴───────────────────────┴─────┴─────┴─────┴─────┘
        map = <

        // Esc      1        2        3        4        5        6        7        8        9        0        Del
           RC(6,6)  RC(0,4)  RC(1,4)  RC(2,4)  RC(3,4)  RC(4,4)  RC(5,4)  RC(0,7)  RC(1,7)  RC(2,7)  RC(3,7)  RC(4,7)

        //     Q        W        E        R        T        Y        U        I        O        P        Ent
               RC(0,6)  RC(1,6)  RC(2,6)  RC(3,6)  RC(4,6)  RC(5,6)  RC(0,5)  RC(1,5)  RC(2,5)  RC(3,5)  RC(5,5)

        // Tab      A        S        D        F        G        H        J        K        L        ' ~
           RC(0,3)  RC(1,3)  RC(2,3)  RC(3,3)  RC(4,3)  RC(5,3)  RC(0,2)  RC(1,2)  RC(2,2)  RC(4,5)  RC(5,7)

        //     L. Sft   Z        X        C        V        B        N        M        ?        Up       R. Sft
               RC(6,0)  RC(0,1)  RC(1,1)  RC(2,1)  RC(3,1)  RC(4,1)  RC(5,1)  RC(3,2)  RC(4,2)  RC(2,0)  RC(6,1)

        //     L. Ctl   Fn       Mnu                    Space                 , /      Lft      Dwn      Rgt
               RC(6,3)  RC(6,2)  RC(6,5)                RC(1,0)               RC(3,0)  RC(4,0)  RC(5,2)  RC(5,0)
      >;
    };

};

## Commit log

2018-02-10 Very first prototype.
    This supports some level of scanning and outputting some key rows.
2018-02-23 Some prototype code for interacting with the keyboard.
2018-02-24 Arduino directory structure and lookup table.
2018-02-25 Switch over to HID keycodes.
2018-02-25 Fn, Menu, and Esc now working.
2018-02-28 Restore the escape key.
    It doesn’t seem to function as I would expect right now.
    [hid_keyboard.ino]
2018-03-02 Switch to using the RX pin (6) instead of DFU for the column.
    This change also required no longer configuring the serial console.
    [hid_keyboard.ino]
2018-03-04 Initial addition of PCB.
    [Psion Keyboard.brd, Psion Keyboard.sch]
2018-03-04 Basic shape.
    [Psion Keyboard.brd]
2018-03-04 Add mounting holes.
    [Psion Keyboard.brd]
2018-03-04 Basic board shape.
    [Psion Keyboard.brd]
2018-03-04 Ignore .job files. General shape.
    [Psion Keyboard.brd]
2018-03-04 Add drill holes.
    [Psion Keyboard.brd]
2018-03-15 Update eagle version.
    [Psion Keyboard.sch]
2018-03-15 Update pins for the new PCB
    Includes drive-by fix for right shift.
    [firmware.ino]
2018-03-25 Initial work on v2 of the PCB.
    [psiboard.brd, psiboard.sch]
2018-03-25 Starting to get to the correct board shape.
    [psiboard.brd]
2018-03-25 Basic board layout now complete, including silkscreen names.
    [psiboard.brd]
2018-03-25 General board layout improvements.
    [psiboard.brd]
2018-03-25 General shape now seems correct, as does the silkscreening.
    [psiboard.brd]
2018-03-25 Schematic is now complete.
    [psiboard.brd, psiboard.sch]
2018-03-25 Routing complete.
    [psiboard.brd]
2018-03-25 Lowercase v for version.
    [psiboard.brd]
2018-03-25 Remembering to add holes.
    [psiboard.brd]
2018-03-25 Remove the v1 PCB.
    [Psion Keyboard.brd, Psion Keyboard.sch]
2018-03-25 Add some notes on the changes made to v1.1 of the PCB.
2018-04-07 Add the STL files for the case.
    [Case v1.stl, Case v2.stl]
2018-04-07 Update the firmware for the latest PCB.
2018-04-11 Some minor adjustments to the case dimensions
    Includes a first guess at a board mounting height.
    [Case v3.stl]
2018-04-12 Set up Fusion sync.
    [psiboard.brd]
2018-07-31 Checking in the first prototype of the USB-C breakout board.
    [breakout.brd, breakout.sch]
2018-07-31 Board design is generally working
    [psiboard.brd, psiboard.sch]
2018-07-31 Update the board.
    [psiboard.brd]
2018-07-31 Fix the routing fro the USB.
    [psiboard.brd]
2018-07-31 Update with Fusion sync.
    [psiboard.brd]
2021-02-17 Add an export of the Fusion 360 models.
    The dimensions of these aren't quite right at the moment, but they're intended to help others get started while the project is idle.
    [Psion Keyboard Case.f3d, Psion Keyboard.f3d]
2025-10-06 Move the PCB into the v1 directory
    [psiboard.brd, psiboard.sch]
2025-10-07 Remove legacy breakout board
    [breakout.brd, breakout.sch]
2025-10-07 Remove proof-of-concept Raspberry Pi polling scripts
2025-10-07 Move the legacy Fusion 360 case designs into `v1`
    [Psion Keyboard Case.f3d, Psion Keyboard.f3d]
2025-10-07 Move the legacy STL exports into the v1 folder
    [Case v1.stl, Case v2.stl, Case v3.stl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]
2025-10-07 Move the legacy Eagle component libraries into `v1/pcb`
2025-10-07 Add the nice!nano version of the PCB (#2)
    [524352271.stp, EVQ-P7A01P.step, f32q_20pin_asm.stp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]
2025-10-12 fix(firmware): Remove unnecessary scanning row (#8)
    [psiboard.overlay]
2025-10-14 fix(pcb): Hand-route keyboard to simplify layout (#9)
    This change also introduces a ground plane and makes the PCB
    significantly larger to allow placement of a status LED in future
    iterations.
    [524372271.stp, nicenano.step, psiboard.kicad_sch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]
2025-10-14 chore(pcb): Ignore autosave files (#10)
2025-10-26 feat: Add the first-cut manufacturing exports (#12)
    [Bluetooth Window.stl, Foot.stl, Hinge Left.stl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]
2026-07-18 fix: 📦 Support Zephyr 4.1 (#23)
2026-07-18 feat: 📦 Generate GitHub releases (#24)
2026-07-19 ci: 🐍 Use `changes` and `build-tools` from PyPI (#29)
2026-07-19 ci: ⏰ Enable daily scheduled builds (#30)
2026-08-13 docs: ©️ Update copyright to 2026 (#33)
2026-09-29 docs: ❤️ Add funding links (#34)
